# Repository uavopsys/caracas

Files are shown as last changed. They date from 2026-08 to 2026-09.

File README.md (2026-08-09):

# Caracas — Drone Frame

Parametric drone frame model in OpenSCAD, built on the jl_scad project-box
library and BOSL2 (both bundled in `libs/` — no separate install needed).

## Layout

- `caracas.scad` — main model (frame body, arm supports, slice/export logic)
- `libs/` — bundled libraries (`jl_scad`, `BOSL2`, `eazl.scad`); see `libs/ATTRIBUTION.md`

## Rendering

OpenSCAD runs as a flatpak here (`org.openscad.OpenSCAD`, 2021.01):

```bash
# preview (fast, OpenCSG)
flatpak run org.openscad.OpenSCAD -o preview.png --imgsize=800,600 caracas.scad

# export STL (full CGAL render — slow at fine quality; coarsen while iterating)
flatpak run org.openscad.OpenSCAD -D '$fs=0.5' -D '$fa=6' -o caracas.stl caracas.scad
```

## Parts and slices

Top-level variables in `caracas.scad` (also exposed in the Customizer):

- `part` — `"all"` | `"bottom"` | `"middle"` | `"top"`: which frame slice to render
- `explode` — Z gap (mm) between slices in the `part="all"` view; `0` = assembled
- `z_bottom` / `z_middle` / `z_top` — slice heights; `frame_height` is derived
  from them plus `plate_thickness` and `frame_thickness`

Export a single slice for printing:

```bash
flatpak run org.openscad.OpenSCAD -D 'part="middle"' -o middle.stl caracas.scad
```

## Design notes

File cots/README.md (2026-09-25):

# Caracas build123d parts

This folder contains the current Python/build123d CAD models. Running a part
script exports its generated files (`.stl`, `.step`, and, for some scripts,
`.dxf`) into this folder.

## First-time setup

Python 3.11 is required. From this folder, run:

```bash
./setup.sh
source .venv/bin/activate
```

The first command creates a local `.venv` and installs the versions in
`requirements.txt`. The second command activates it for the current shell.
Repeat only the `source` command when opening a new shell.

If `setup.sh` is not executable after copying the project, run it as:

```bash
bash setup.sh
```

## Generate parts

With the virtual environment active, run any part script directly:

```bash
python arm_hub.py
python plate.py
python motor_mount.py
python canopy.py
```

For example, `python plate.py` creates `plate.step`, `plate.stl`, and
`plate.dxf`. Parameter-tagged models such as the arm hub and motor mount put
their dimensions in the output filename. Shared dimensions are read from
`config.yaml`.

Activation is optional if you call the virtual-environment interpreter
explicitly:

```bash
.venv/bin/python arm_hub.py
```

The optional 3D viewer can be started in a second terminal after activation:

```bash
python -m ocp_vscode
```

The exports are still produced when the viewer is not running. The drawing
scripts (`drawing.py` and `standoff_dimensions.py`) create documentation
images/PDFs rather than STL/STEP parts.

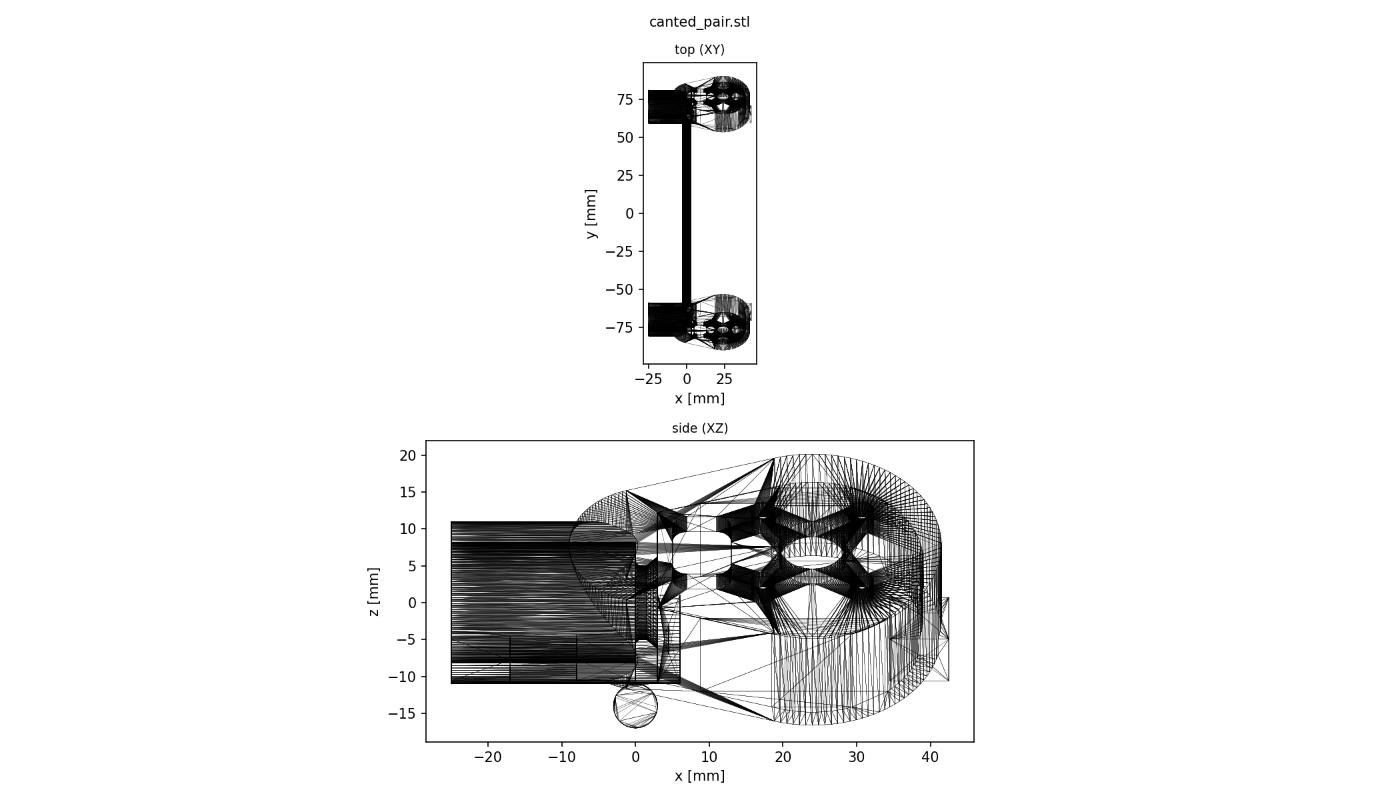
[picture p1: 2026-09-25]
cots/canted_pair_preview.png

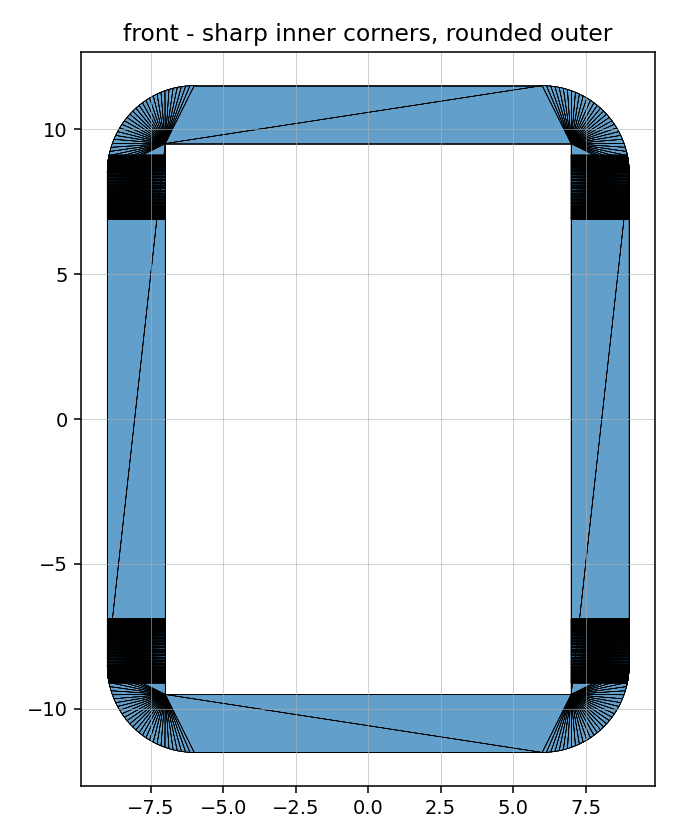
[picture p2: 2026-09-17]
cots/camera_holder_preview.png

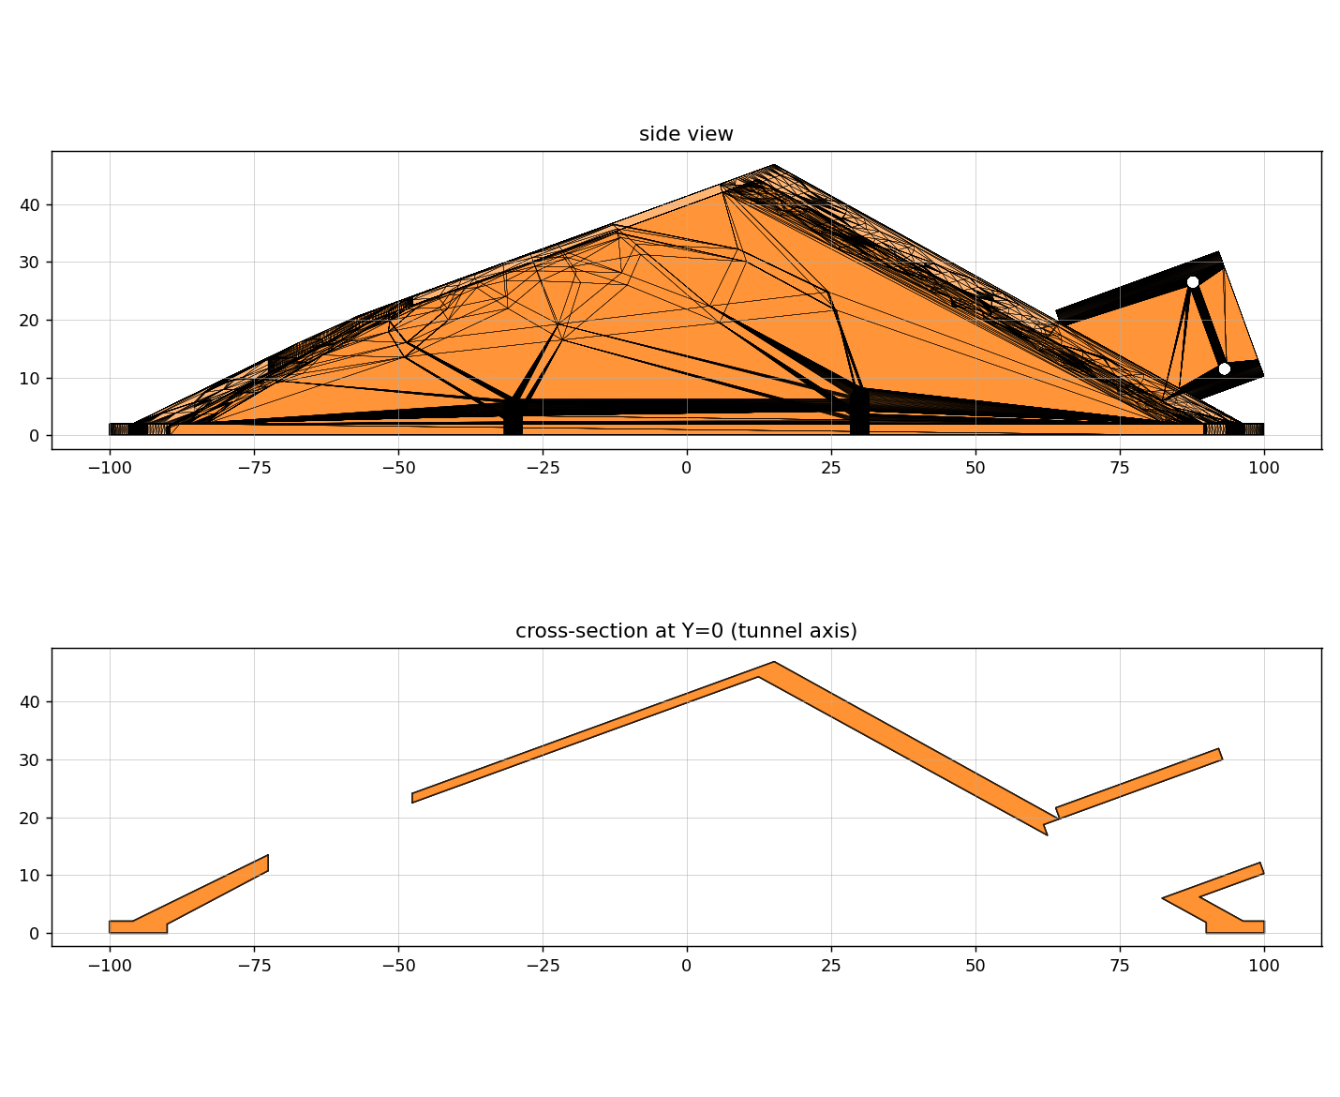
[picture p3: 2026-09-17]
cots/canopy_camera.png

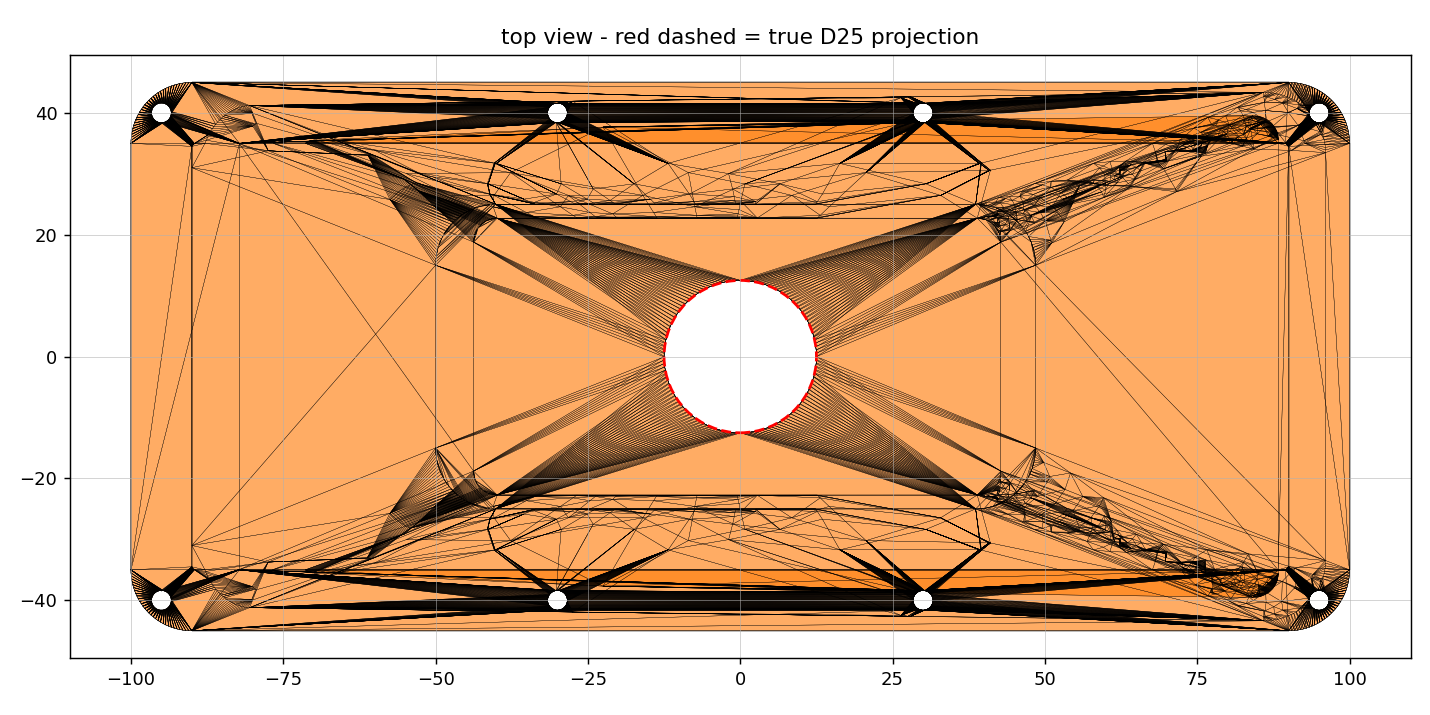
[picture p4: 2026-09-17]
cots/canopy_cutout.png

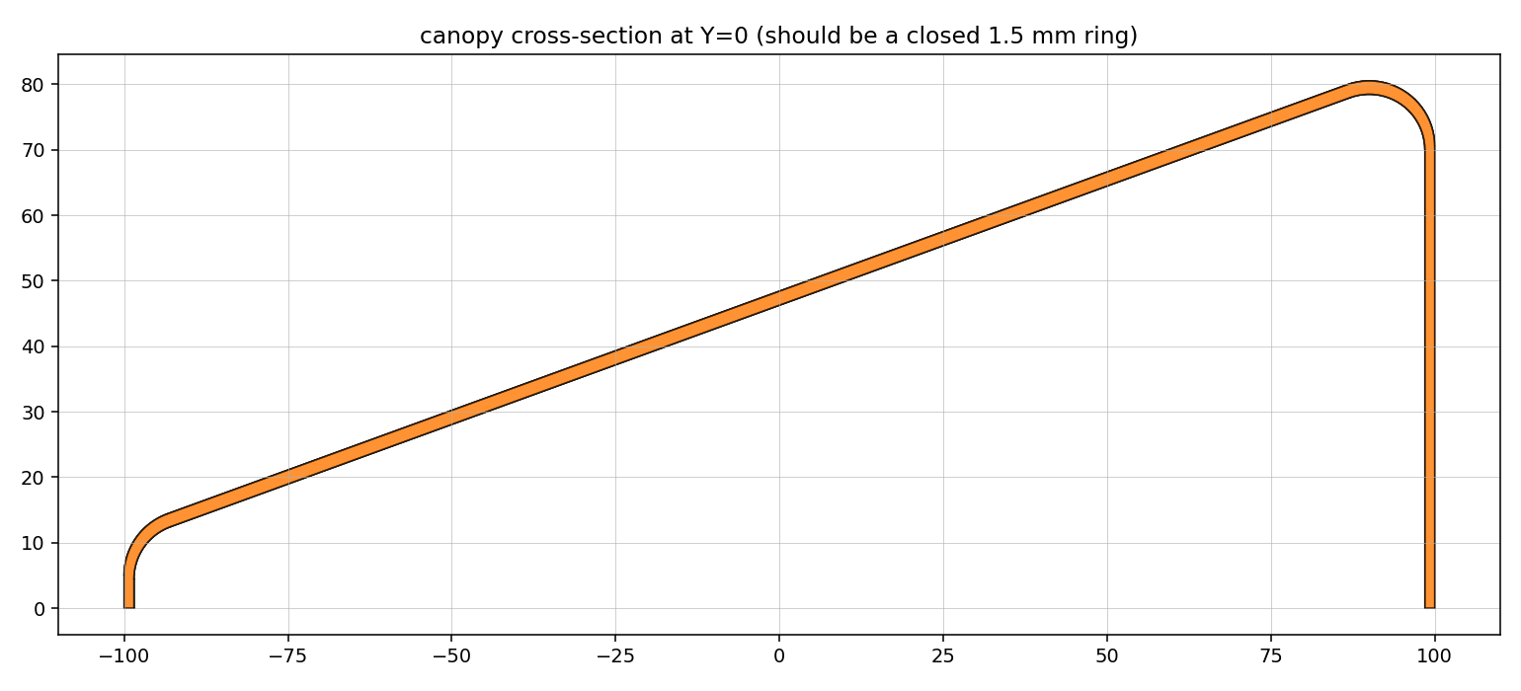
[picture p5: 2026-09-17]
cots/canopy_section.png

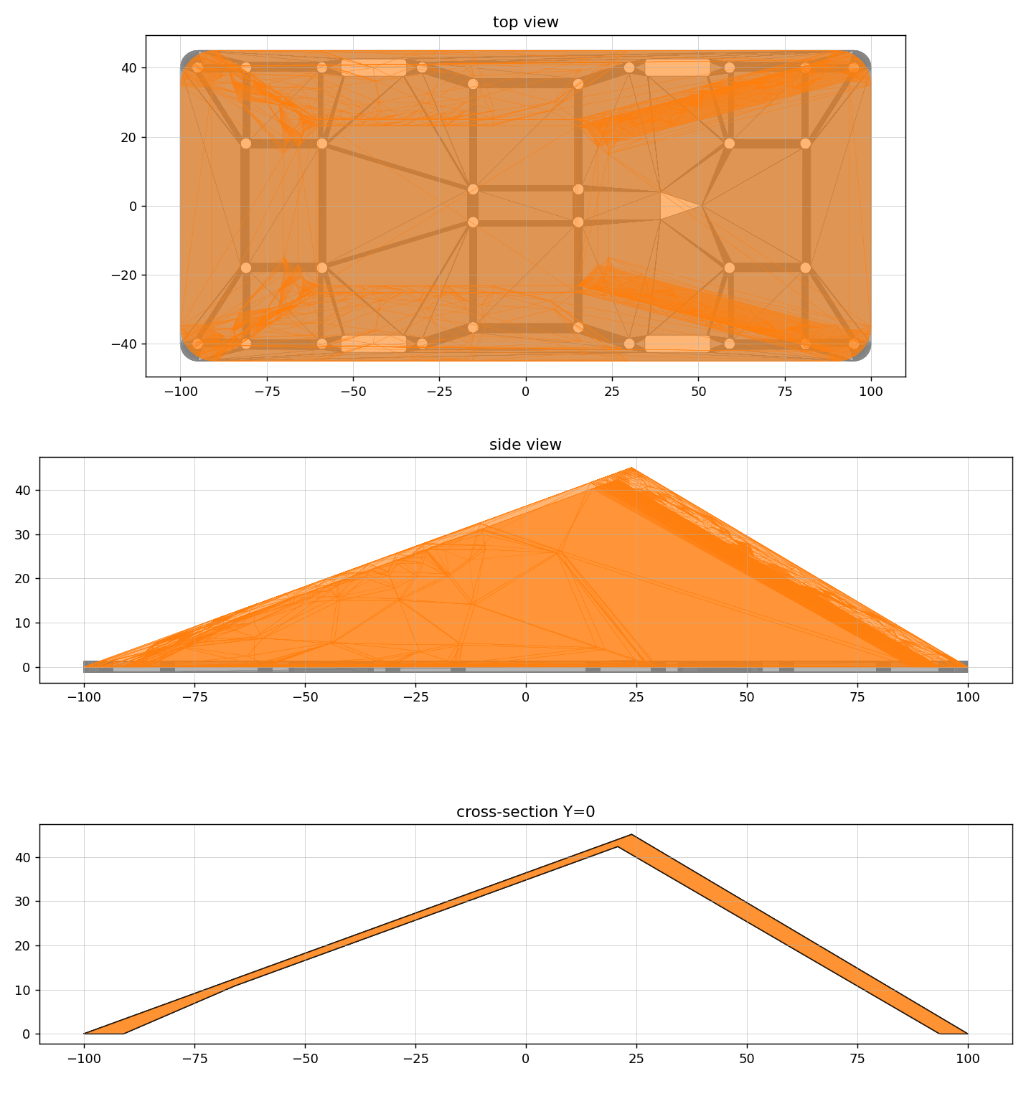
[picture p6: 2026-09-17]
cots/canopy_preview.png

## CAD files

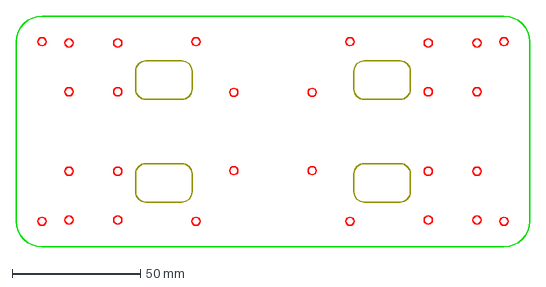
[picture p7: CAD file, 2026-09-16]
mvp/plate.dxf
200.0 x 90.0 mm

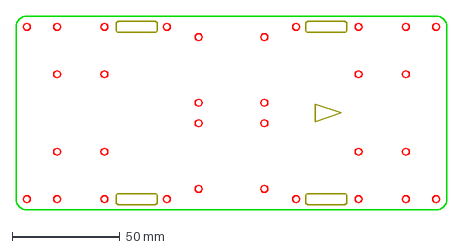
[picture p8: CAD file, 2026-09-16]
cots/plate.dxf
200.0 x 90.0 mm

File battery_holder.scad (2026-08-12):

/**
 * Battery Holder
 * ==============
 * Secure mounting system for FullSend 10A batteries
 *
 * Self-contained: all parameters and helper modules live in this file.
 */

// =============================================================================
// PARAMETERS
// =============================================================================

// FullSend 10A battery dimensions (mm)
BATTERY_LENGTH = 160;
BATTERY_WIDTH = 67;
BATTERY_DEPTH = 47;
BATTERY_CLEARANCE = 2.3;  // inner spacing around battery

// Strap handle dimensions (mm)
STRAP_HANDLE_THICKNESS = 4;
STRAP_HANDLE_WIDTH = 8;
STRAP_HANDLE_HEIGHT = 5;

// =============================================================================
// STRAP HANDLE
// =============================================================================

/**
 * Strap Handle - zip-tie or velcro strap loop
 * Used for securing the battery to the bay
 */
module strap_handle() {
    thickness = STRAP_HANDLE_THICKNESS;
    width = STRAP_HANDLE_WIDTH;
    height = STRAP_HANDLE_HEIGHT;

    difference() {
        // Outer block
        cube([22 + 2*thickness, width, height + thickness], center=true);

        // Inner cutout for strap
        cube([22, width + 1, height], center=true);
    }
}

// =============================================================================
// FULLSEND 10A BATTERY BAY
// =============================================================================

/**
 * FullSend 10A Battery Holder
 *
 * Features:
 *   - Protective enclosure with one open side for easy insertion
 *   - Multiple strap handle positions for secure retention
 *   - Handles on rear, middle-front, and middle-back
 *   - Optimized for 160x65x45mm battery pack
 *
 * Battery Specifications:
 *   - Length: 160mm
 *   - Width: 65mm
 *   - Depth: 45mm
 */
module fullsend10a_battery_bay() {
    inner_space = BATTERY_CLEARANCE;
    batt_length = BATTERY_LENGTH;
    batt_width = BATTERY_WIDTH;
    batt_depth = BATTERY_DEPTH;

    // =========================================================================
    // Main Battery Enclosure
    // =========================================================================

    difference() {
        // Outer shell
        cube([
            batt_length + 2*inner_space,
            batt_width + 2*inner_space,
            batt_depth + 2*inner_space
        ], center=true);

        // Inner cavity (offset for single open side)
        translate([inner_space, 0, 0])
            cube([
                batt_length + inner_space,
                batt_width,
                batt_depth
            ], center=true);
    }

    // =========================================================================
    // Strap Handles - Rear Position
    // =========================================================================

    // Rear left handle
    rotate([0, -90, 0])
        translate([10, batt_width/2 + 5, -batt_length/2 - 5])
            strap_handle();

    // Rear right handle
    rotate([0, -90, 0])
        translate([10, -batt_width/2 - 5, -batt_length/2 - 5])
            strap_handle();

    // =========================================================================
    // Strap Handles - Middle-Front Position (Bottom)
    // =========================================================================

    // Front-left position 1
    translate([batt_length/12, -batt_width/2 - 5, -batt_depth/2 + 1.75])
        rotate([90, 0, 0])
            strap_handle();

    // Front-left position 2
    translate([-batt_length/12, -batt_width/2 - 5, -batt_depth/2 + 1.75])
        rotate([90, 0, 0])
            strap_handle();

    // Front-left position 3
    translate([batt_length/4, -batt_width/2 - 5, -batt_depth/2 + 1.75])
        rotate([90, 0, 0])
            strap_handle();

    // Front-left position 4
    translate([-batt_length/4, -batt_width/2 - 5, -batt_depth/2 + 1.75])
        rotate([90, 0, 0])
            strap_handle();

    // =========================================================================
    // Strap Handles - Middle-Back Position (Top)
    // =========================================================================

    // Back-right position 1
    translate([batt_length/12, batt_width/2 + 5, -batt_depth/2 + 1.75])
        rotate([90, 0, 0])
            strap_handle();

    // Back-right position 2
    translate([-batt_length/12, batt_width/2 + 5, -batt_depth/2 + 1.75])
        rotate([90, 0, 0])
            strap_handle();

    // Back-right position 3
    translate([batt_length/4, batt_width/2 + 5, -batt_depth/2 + 1.75])
        rotate([90, 0, 0])
            strap_handle();

    // Back-right position 4
    translate([-batt_length/4, batt_width/2 + 5, -batt_depth/2 + 1.75])
        rotate([90, 0, 0])
            strap_handle();
            
    // ======================================================================
    // wire passage
    // ======================================================================
    translate([0, batt_width/2-3 , -batt_depth/2 - 7])
        cube ([batt_length,10,12],center=true);
    translate([0, -batt_width/2+3, -batt_depth/2 -7])
        cube ([batt_length,10,12],center=true);


}

// =============================================================================
// USAGE EXAMPLES (uncomment to render)
// =============================================================================

// Render battery bay
fullsend10a_battery_bay();

// =============================================================================
// PRINTING NOTES
// =============================================================================

/*
 * Recommended Print Settings:
 *   - Layer Height: 0.2mm - 0.3mm
 *   - Wall Count: 3-4 perimeters
 *   - Infill: 20-30% gyroid or honeycomb
 *   - Support: May need support for strap handles depending on orientation
 *
 * Recommended Orientation:
 *   - Print with battery opening facing up for minimal supports
 *   - Strap handles may need light support material
 *
 * Post-Processing:
 *   - Test fit battery before installing
 *   - Use 20-25mm wide velcro/battery straps
 *   - Ensure clearance is adequate (adjust BATTERY_CLEARANCE above if needed)
 */

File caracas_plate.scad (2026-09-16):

include <libs/jl_scad/utils.scad>
include <libs/jl_scad/box.scad>
include <libs/jl_scad/parts.scad>

// caracas plate
frame_width=90;
frame_length=200;
plate_thickness=2.5;
case_rounding=25;



module m3_hole(){
    cylinder(h=10,d=3.2,center=true);
}


module foldable_axis(){
        hole_distance=22;
        m3_hole = 3.1;
        
        rotate([0,0,90]) 
        {
            translate([0,hole_distance,0]) cylinder(h=plate_thickness*2,r=m3_hole/2,center=true);
            translate([0,-hole_distance,0]) cylinder(h=plate_thickness*2,r=m3_hole/2,center=true);
        }
        translate([0, -hole_distance,0]) rotate([0,0,90]) 
        {
            translate([0,hole_distance,0]) cylinder(h=plate_thickness*2,r=m3_hole/2,center=true);
            translate([0,-hole_distance,0]) cylinder(h=plate_thickness*2,r=m3_hole/2,center=true);
        }
 
}


 // one plate sized to the shell cross-section at height z (its center)
module support_plate() {
    cuboid([frame_length, frame_width , plate_thickness],
           rounding=case_rounding, edges="Z");
}

module support_holes(){
    
}
support_plate();
translate ([10,0,10]) foldable_axis();

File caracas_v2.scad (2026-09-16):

/**
 * Caracas - Drone Frame
 * =====================
 * Uses the jl_scad project-box library (built on BOSL2)
 * for cases, bodies and rounded curvature.
 */

include <libs/jl_scad/utils.scad>
include <libs/jl_scad/box.scad>
include <libs/jl_scad/parts.scad>

// battery bay module (modules only — its own top-level render call is not executed)
use <battery_holder.scad>

$fs = $preview ? 0.5 : 0.125;
$fa = 5;

// =============================================================================
// PARAMETERS — everything tunable lives in this block
// =============================================================================

// ---- props & frame ----
prop_size       = 110;           // prop radius; 8 inch ≈ 110mm
frame_length    = prop_size*2;   // keeps propellers from colliding
frame_width     = 100;
frame_thickness = 3;             // case wall thickness
case_rounding   = 25;            // case corner rounding

// ---- support plates (carbon fiber) ----
plate_thickness = 2.5;
plate_clearance = 5;             // per-side gap from the case shell

// ---- slice heights ----
z_top    = 30;  // top slice; 28 to make space for folding arms
z_middle = 45;  // middle slice (centered on z=0); 45 to make space for battery
z_bottom = 30;  // bottom slice

// ---- arms (carbon rods) ----
arms_inner_diameter = 16;        // rod diameter
arms_wall_thicklness = 3;        // support wall strength
arms_support_length = 30;
arms_from_edge = prop_size/2-10;      // rod distance from frame end (keeps prop out of sight)

// arm pairs: A+D is one rod (+x), B+C is one rod (-x).
// z is referenced from the "top"/"bottom" outer face; _z_off = mm inward from it.
// e.g. ref="top", off=5 puts the rod 5mm below the top face.
arm_ad_x     = frame_length/2 - arms_from_edge;
arm_ad_z_ref = "top";
arm_ad_z_off = z_top/2+arms_wall_thicklness-plate_thickness;

arm_bc_x     = -(frame_length/2 - arms_from_edge);
arm_bc_z_ref = "bottom";
arm_bc_z_off = z_bottom/2+arms_wall_thicklness-plate_thickness;


// ---- battery bay (separate printed part, fit-check only) ----
show_battery_bay = false;        // also toggles the d_parts() visual guides
show_props = false;        // toggle proppeler view
battery_bay_pos  = [0, 0, 0];    // bay center in frame coords (mm)

// ---- view ----
show_support_plates = true;
part      = "all";               // "all" | "bottom" | "middle" | "top"
explode   = 50;                  // z gap between slices when part="all" (0 = assembled)
explode_y = 200;                   // slides fit-check parts out in y (plates +y, bay -y)

// ---- battery reference dims (unused by the model; bay dims live in battery_holder.scad)
battery_width  = 65;             // iflight fullsend battery
battery_height = 45;
battery_length = 160;

// =============================================================================
// DERIVED VALUES — computed from the parameters above; do not edit directly
// =============================================================================

frame_height = frame_thickness+z_top+plate_thickness+z_middle+plate_thickness+z_bottom+frame_thickness;

arm_ad_z = arm_z(arm_ad_z_ref, arm_ad_z_off);
arm_bc_z = arm_z(arm_bc_z_ref, arm_bc_z_off);

shell_rim_z = frame_height/2 - case_rounding;  // height where the shell starts curving in



// hollow cylinder: inner D 16, wall 5, length 10, rounded rims
// (rounding is capped at wall/2 = 2.5)
module arm_support(height){
    depth= (frame_width-frame_thickness*1.5)/2;
        rotate([-90,90,0]){
            translate([0,0,-arms_support_length/4])tube(id=arms_inner_diameter, wall=arms_wall_thicklness, h=arms_support_length, rounding=2, center=true);
            *translate([0,0,depth/2])cube([arms_inner_diameter*2, (frame_width-frame_thickness*1.5)/2, height],center=true);
        }

}


module body() {
    
difference(){
    union(){
        // 20x20x20 cube with curvature on all sides
        difference(){
            cuboid([frame_length, frame_width, frame_height], rounding=case_rounding);
                    // hollow the case — inner rounding shrinks by the wall thickness
                    // so the shell stays a uniform 6mm, closed at top/bottom
            cuboid([frame_length-frame_thickness*1.5, frame_width-frame_thickness*1.5, frame_height-frame_thickness*2],
                   rounding=case_rounding-frame_thickness);
        }
    
    
        arm_pair_ad();  // A front, D back — one rod
        arm_pair_bc();  // B front, C back — one rod
    }          

// open the walls where the arms will go
translate([arm_ad_x,0,arm_ad_z]) rotate([90,0,0]) cylinder(h=500,d=16,center=true);
translate([arm_bc_x,0,arm_bc_z]) rotate([90,0,0]) cylinder(h=500,d=16,center=true);
}
    
}





// ---- arm pairs --------------------------------------------------------
// Arms are carbon fiber rods in an H configuration; each pair (A+D, B+C)
// is one continuous rod held by two supports. Placement params are at the top.
function arm_z(ref, off) = ref == "top" ? frame_height/2 - off
                                        : -frame_height/2 + off;

// explode offset of the slice a pair belongs to (top slice moves up, bottom down)
function pair_explode(ref) = part == "all" ? (ref == "top" ? explode : -explode) : 0;

module arm_pair_ad() {
    h = arm_ad_z_ref == "top" ? z_top : z_bottom;
    //A (front)
    translate([arm_ad_x,-frame_width/2+frame_thickness,arm_ad_z]) arm_support(height=h);
    //D (back)
    translate([arm_ad_x,frame_width/2-frame_thickness,arm_ad_z]) rotate([180,0,0]) arm_support(height=h);
}

module arm_pair_bc() {
    h = arm_bc_z_ref == "top" ? z_top : z_bottom;
    //B (front)
    translate([arm_bc_x,-frame_width/2+frame_thickness,arm_bc_z]) arm_support(height=h);
    //C (back)
    translate([arm_bc_x,frame_width/2-frame_thickness,arm_bc_z]) rotate([180,0,0]) arm_support(height=h);
}

// ---- support plates (carbon fiber — separate parts, not printed) ------
// Four plates: one inside the top case, one on each side of the middle
// cut, one inside the bottom case. Each plate follows the case shell
// cross-section at its own height: middle plates sit where the shell is
// full-size; top/bottom plates where it has curved inward — so smaller.
// Params (plate_thickness, plate_clearance, show_support_plates) are at the top.

// shell cross-section at height z: inward offset and corner radius there
function shell_inset(z)  = abs(z) <= shell_rim_z ? 0
    : case_rounding - sqrt(case_rounding*case_rounding - pow(abs(z) - shell_rim_z, 2));
function shell_corner(z) = abs(z) <= shell_rim_z ? case_rounding
    : sqrt(case_rounding*case_rounding - pow(abs(z) - shell_rim_z, 2));

// one plate sized to the shell cross-section at height z (its center)
module support_plate(z) {
    inset = shell_inset(z) + plate_clearance;
    cuboid([frame_length - 2*inset, frame_width - 2*inset, plate_thickness],
           rounding=max(0, shell_corner(z) - plate_clearance), edges="Z");
}


module m3_hole(){
    cylinder(h=10,d=3.2,center=true);
}


module pattern(){
      x_shift=50;
      y_shift=15;
      z_rotate = 10;
    
      translate([x_shift,0,0]){
      rotate([0,0,z_rotate]) translate([0,y_shift,0]) cuboid([50,10,30], rounding=3, edges="Z");
      rotate([0,0,-z_rotate]) translate([0,-y_shift,0]) cuboid([50,10,30], rounding=3, edges="Z");
      }
      translate([-x_shift,0,0]){
      rotate([0,0,z_rotate]) translate([0,y_shift,0]) cuboid([50,10,30], rounding=3, edges="Z");
      rotate([0,0,-z_rotate]) translate([0,-y_shift,0]) cuboid([50,10,30], rounding=3, edges="Z");
      }



}

**translate ([0,explode_y,100]) pattern();



module foldable_axis(){
        hole_distance=22;
        padding = 6;
        m3_hole = 3.1;
        radius=hole_distance*cos(45/2)+padding+m3_hole;
        thickness=plate_thickness*1.5;
        
        difference(){
            cylinder(h=thickness,r=radius,center=true);
            translate([0,hole_distance*cos(45/2),0]) cylinder(h=plate_thickness*2,r=m3_hole/2,center=true);
            translate([0,-hole_distance*cos(45/2),0]) cylinder(h=plate_thickness*2,r=m3_hole/2,center=true);
            translate([hole_distance*cos(45/2),0,0]) cylinder(h=plate_thickness*2,r=m3_hole/2,center=true);
            translate([-hole_distance*cos(45/2),0,0]) cylinder(h=plate_thickness*2,r=m3_hole/2,center=true);
        }

}

translate([100,100, 20]) foldable_axis();

module support_plates() {
    z_in   = frame_height/2 - frame_thickness;   // inner top/bottom face of the case
    zc_tb  = z_in - plate_thickness/2;           // true center of the top/bottom plates
    zc_mid = z_middle/2 + plate_thickness/2;     // true center of the middle plates

    //top
    translate([0,0,  zc_tb + pair_explode("top")])    support_plate(zc_tb);
    *translate([0,frame_width/3,  zc_tb + pair_explode("top")]) m3_hole();
    *translate([0,-frame_width/3,  zc_tb + pair_explode("top")]) m3_hole();
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

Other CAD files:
caracas.scad

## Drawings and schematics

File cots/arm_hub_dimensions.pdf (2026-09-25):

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

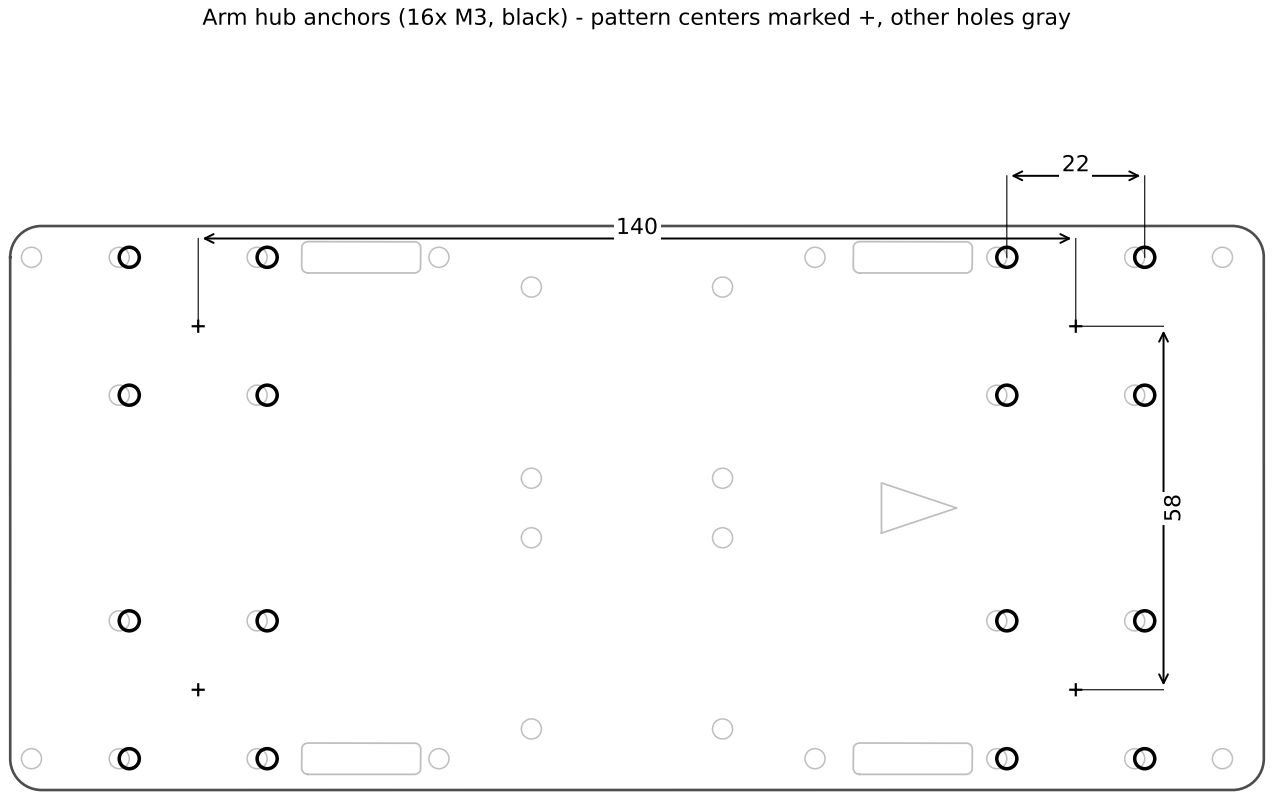
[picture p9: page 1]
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

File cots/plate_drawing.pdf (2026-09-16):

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

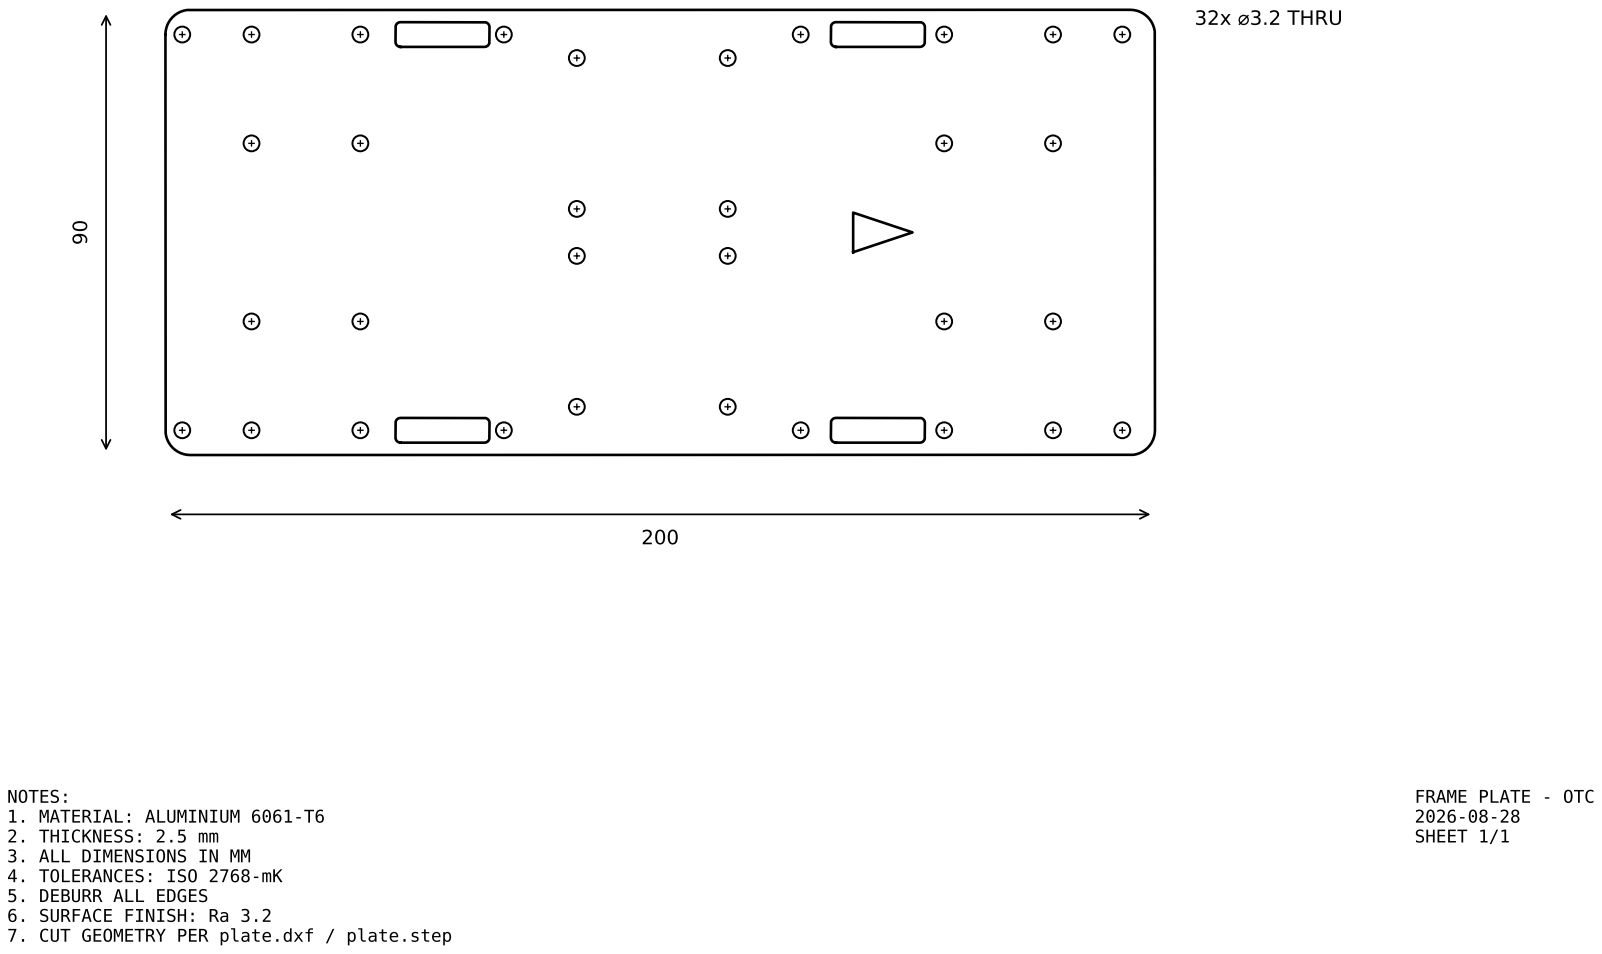
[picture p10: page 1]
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

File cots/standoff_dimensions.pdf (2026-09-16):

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

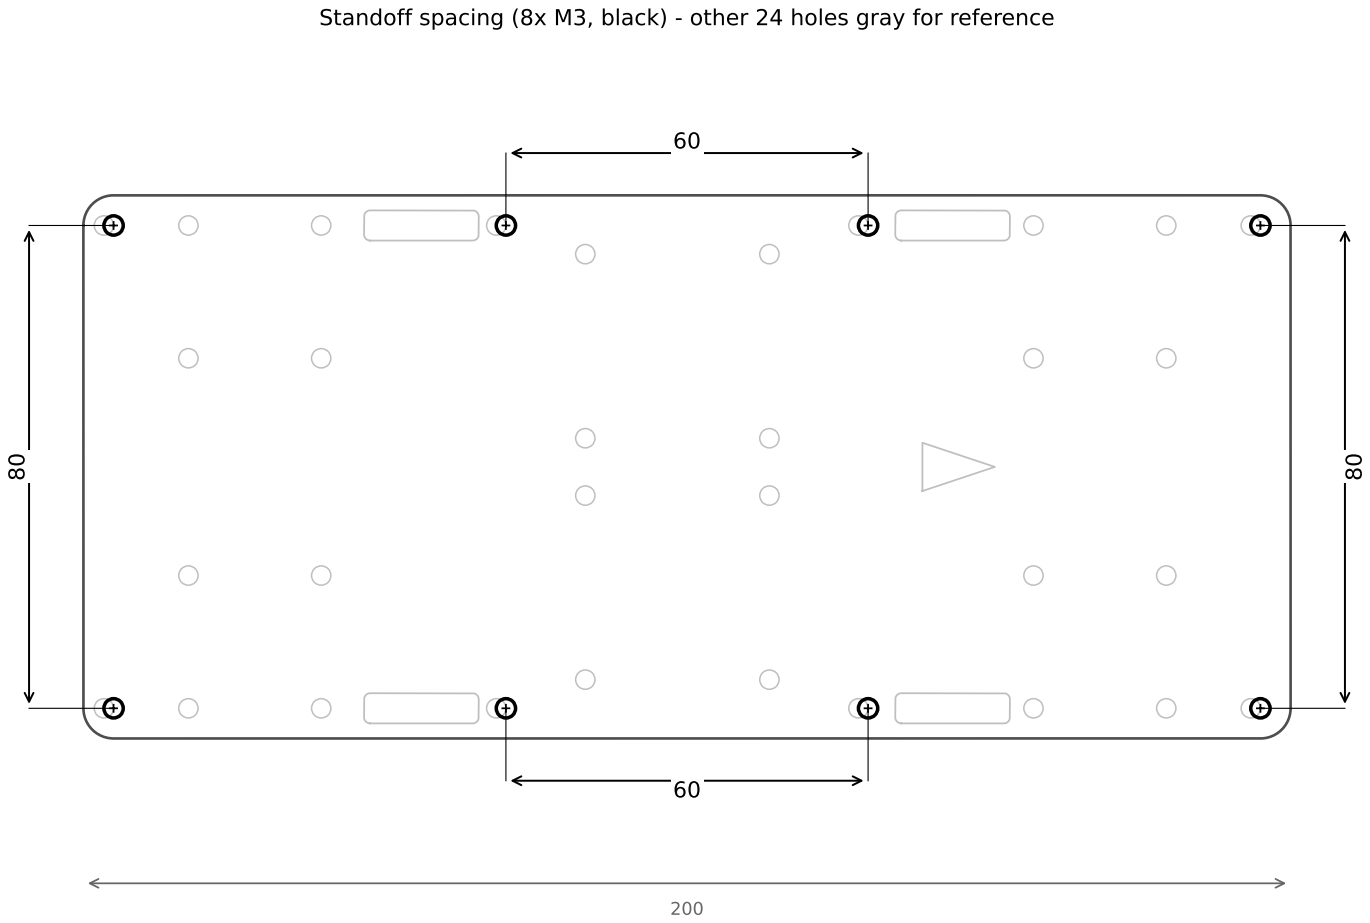
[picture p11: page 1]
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

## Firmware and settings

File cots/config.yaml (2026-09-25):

# COTS variant configuration.
# Values that more than one script must agree on live here; scripts compute
# derived values themselves (e.g. plate.py derives pattern positions from
# hole_grid and corner_standoff_offset).
# The jigs read geometry from plate.step, so they need nothing from this file.

# Arm hub: block holding the D16 carbon rod, bolts onto the plate corners.
arm_hub:
  size: 28            # block edge (X/Y)
  size_height: 22     # block height (Z)
  rod_diameter: 16    # through-bore for the carbon rod (D16)
  rod_clearance: 0.4  # shared arm-tube bore clearance (hub + motor mount)
  screw_diameter: 3   # M3 self-tapping pilot for printed plastic (no insert)
  hole_grid: 22       # 2x2 screw spacing; plate anchor patterns align to this

# Plate: carbon fiber main plate.
plate:
  # ---- plate ----
  frame_length: 200
  frame_width: 90
  plate_thickness: 2.5
  corner_rounding: 5

  # ---- M3 anchor patterns (one per corner) ----
  screw_diameter: 3.2   # M3 clearance (2.5 for tapping)
  pattern_x: 30         # pattern center distance from the plate end (short) edge
  # pattern rotation in degrees. Forward pair: port CCW, starboard CW.
  # Aft pair: reversed (port CW, starboard CCW). Nose is +X, port is +Y.
  pattern_angle_forward: 0
  pattern_angle_aft: 0

  # ---- standoff holes (8 total: 4 corner + 4 middle) ----
  standoff_diameter: 3.2          # M3 standoff screws
  corner_standoff_offset: 5       # corner hole center distance from each edge
  middle_standoff_edge_offset: 5  # middle hole center distance from the long edge
  middle_standoff_x: 30           # middle hole distance from plate center along X

  # ---- flight controller mounts: concentric M3 grids,
  #      mirrored across the centerline so either side can take a stack ----
  fc_pattern_spacings: [30.5]
  # fc_pattern_spacings: [30.5, 25.5, 20]  # uncomment to add 25.5 + 20 grids
  fc_hole_diameter: 3.2
  fc_x: 0               # pattern center along the length
  fc_y: 20              # pattern center along the width
  fc_mirror: true       # duplicate the patterns on the mirror side (y -> -y)

  # ---- lightening slots (weight reduction in the low-stress web) ----
  lightening: true
  slot_length: 19       # along X
  slot_width: 5        # along Y
  slot_radius: 1        # corner fillet - generous radii, sharp corners start cracks
  slot_gap_from_anchor: 26  # slot center this far inward from the anchor pattern
  slot_y: 40

  # ---- forward marker: small arrow cut into the web, points at the nose (+X) ----
  fwd_arrow: true
  arrow_x: 45           # arrow center along the length, on the centerline
  arrow_size: 12        # overall arrow length
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

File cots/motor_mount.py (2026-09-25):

"""
D16 'droplet' motor mount - teardrop shell cantilevered past the END of the
16mm carbon arm tube, carrying a 2812-size brushless motor on a flat
platform. The whole part lives inside the arm hub's vertical envelope:
centered bore at z=0, platform top at exactly +size_height/2 (11mm), nothing
below -size_height/2 (-11mm). Flush tops and bottoms with the arm hub ARE
the leveling mechanism (see below).

Geometry (shared values from config.yaml; the arm tube dimensions come from
the arm_hub section and mount-specific values from motor_mount):
- BLIND bore (glue well) = rod_diameter + rod_clearance = 16.4mm: the tube
  inserts insertion_depth (25mm) from the hub-facing end and bottoms against
  a stop face. Past the stop a 10mm hole opens into the droplet's hollow
  cavity, so the carbon tube's open end faces the cavity - the motor cable
  gets into the tube through it, no drilling.
- teardrop plan along the tube axis: round end (2 x droplet_radius, ~35mm
  across) carries the motor, tapering back to the D22 sleeve. Platform skin
  (3mm) at z=+11: 4x 3.2mm holes on a 19mm bolt circle at 45/135/225/315 deg
  (from skyfold's motor_adapter_19_25.scad), a 9mm center hole, and the cable
  opening (rounded rectangle, cable_slot_width x cable_slot_x1-x0) BETWEEN
  the bolt circle and the arm - like the classic aluminum clamp mounts, the
  motor leads exit the motor's rear edge and drop straight through into the
  cavity, then through the stop hole into the tube. No bend, no exposed wire.
- open bottom: a perimeter skirt (skirt_thickness) follows the droplet
  outline from the skin underside down to skirt_bottom_z like a shallow boat
  hull; the cavity is open from below so the M3 bolt heads (bolts come up
  from below into the motor's threaded base) are accessible. Two side ribs
  stiffen the skin, clear of the cable raceway and the head envelopes.
- leveling feet: three foot_size squares with bottoms at exactly z=-11 - a
  3-point stance (the round sleeve alone can't sit flat). Leveling: set the
  mount on a flat table next to the arm hub (or press both against a
  straightedge) while the epoxy cures; flush bottoms (-11) and tops (+11)
  guarantee rotational alignment.
- cable funnel: trumpet flare (10 -> 15mm) on the cavity side of the stop
  hole plus a small rim chamfer on the tube side, so wires feeding into the
  tube end are guided and the tube tip doesn't catch a sharp rim.

Print: platform skin DOWN on the bed (part flipped from its installed
orientation), bore axis horizontal - the open cavity faces up and needs no
supports; the blind bore prints as a horizontal hole, hence rod_clearance
0.4mm total for bridging sag (same reasoning as arm_hub.py).

Run with the ocp_vscode standalone viewer running (python3.11 -m ocp_vscode),
or headless: exports motor_mount-<rod_diameter>-<rod_clearance>.step/.stl
next to this file.
"""

import math
import os
from pathlib import Path

import yaml
from build123d import *

os.chdir(Path(__file__).parent)  # outputs land next to this script

# =============================================================================
# PARAMETERS — from config.yaml
# =============================================================================

with open("config.yaml") as f:
    config = yaml.safe_load(f)

cfg = config["motor_mount"]
arm_cfg = config["arm_hub"]

rod_diameter = arm_cfg["rod_diameter"]    # shared D16 carbon arm tube
rod_clearance = arm_cfg["rod_clearance"]  # shared horizontal-bore clearance
sleeve_diameter = cfg["sleeve_diameter"]  # ~3mm wall over the rod
insertion_depth = cfg["insertion_depth"]  # blind bore: tube bottoms against the stop
stop_hole_diameter = cfg["stop_hole_diameter"]  # cable pass at the bore's inner end
droplet_radius = cfg["droplet_radius"]    # round end carrying the motor
droplet_center_x = cfg["droplet_center_x"]  # round end center, outboard of the stop
skin_thickness = cfg["skin_thickness"]    # platform top skin
skirt_thickness = cfg["skirt_thickness"]  # perimeter wall around the open cavity
skirt_bottom_z = cfg["skirt_bottom_z"]    # skirt lower edge; cavity open below
motor_bcd = cfg["motor_bcd"]              # 2812 bolt circle, 4x M3 at the 45 deg diagonals
motor_hole_diameter = cfg["motor_hole_diameter"]
center_hole_diameter = cfg["center_hole_diameter"]
cable_slot_x0 = cfg["cable_slot_x0"]  # cable opening, tube-side end
cable_slot_x1 = cfg["cable_slot_x1"]  # motor-side end (behind the rear bolt holes)
cable_slot_width = cfg["cable_slot_width"]
foot_size = cfg["foot_size"]              # 3 leveling feet

# vertical envelope: the arm hub is a size x size x size_height block with a
# centered bore, so its faces sit at +/- size_height/2 - the mount shares both
# planes (platform top at +env, feet bottoms at -env).
env = config["arm_hub"]["size_height"] / 2  # 11.0

# =============================================================================
# DERIVED
# =============================================================================

bore_diameter = rod_diameter + rod_clearance  # 16.4
bore_radius = bore_diameter / 2
sleeve_radius = sleeve_diameter / 2

skin_top_z = env                       # platform top: flush with the arm hub top
skin_bottom_z = skin_top_z - skin_thickness

# X layout: the bore stop face is at x=0; the tube/sleeve extends in -X
# (toward the arm hub), the droplet cantilevers outboard in +X.
sleeve_x0 = -insertion_depth           # tube entry face
stop_x1 = 3                            # stop wall thickness: x 0..3
funnel_x1 = 6                          # cable funnel: x 3..6
sleeve_x1 = funnel_x1                  # sleeve reaches into the droplet neck
neck_x = 2                             # teardrop neck circle center (on the sleeve)

hole_xy = motor_bcd / (2 * math.sqrt(2))  # hole center on each axis (+/-6.72)
motor_x = droplet_center_x             # motor pattern center
skin_mid_z = (skin_bottom_z + skin_top_z) / 2  # cuts centered here pierce the skin
slot_cx = (cable_slot_x0 + cable_slot_x1) / 2
slot_len = cable_slot_x1 - cable_slot_x0

# M3 socket head envelope (heads sit in the open cavity under the skin)
head_diameter = 5.5
head_height = 3.0

# ribs stiffening the skin: along X at the cavity sides, clear of the cable
# raceway (|y| <= 5 around the stop hole) and of the head envelopes (rim at
# |y| = hole_xy + head_diameter/2 = 9.47)
rib_y0 = 11
rib_thickness = 3

# leveling feet: two on the sleeve fore/aft, one under the droplet tip
feet = [(sleeve_x0 + 4, 0), (-4, 0), (droplet_center_x + droplet_radius - foot_size / 2 + 1, 0)]

# =============================================================================
# PART
# =============================================================================
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

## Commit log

2026-08-09 initial: caracas drone frame (body, arm supports, 3-slice z export)
    [caracas.scad]
2026-08-12 import speedybee fold 8 battery bay sources (reference snapshot)
    [FPV_Leg.scad, battery_holder.scad, common_modules.scad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]
2026-08-12 battery bay self-contained; arm pairs, support plates, fit-check overlays in caracas
    - battery_holder.scad: inline config constants + strap_handle, drop speedybee includes
    - remove speedybee scaffold files (config/common_modules/FPV_Leg)
    - caracas.scad: parametric arm pairs (A+D, B+C) with top/bottom z reference,
    visual guides follow z-explode; battery bay + 4 carbon support plates as
    togglable fit-check overlays; explode_y slides overlays out sideways
    [FPV_Leg.scad, battery_holder.scad, caracas.scad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]
2026-09-16 track cots/mvp build123d work, root scad/py sources; ignore CAD exports (stl/step/3mf)
    [caracas_plate.scad, caracas_v2.scad, plate.dxf]
2026-09-17 add canopy, camera_holder, gps_holder to cots; shared config.yaml
    canopy.py: config-driven lofted pod - top plate driven by top_height +
    optional slope_angle, tail exhaust slots, NACA roof ducts, rounded side
    service openings between the middle standoffs (USB/button access), and
    flange cutouts exposing the plate's lightening slots with the channel
    reaching inward for cable routing. Positions follow plate config.
    camera_holder.py / gps_holder.py: standalone sleeve and arc-band parts.
    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
2026-09-20 canopy: standoff screw seats, 160x60x30 top, 28mm cutout
    Pads with head seats per standoff hole plus access wells through the
    shell so screws drop straight in and clamp the pod against vibration;
    top plate grows to 160x60 at 30mm height, projected cutout to 28mm.
    [config.yaml]
2026-09-20 motor_mount: D16 'droplet' motor mount for tube-end installation
    Teardrop shell cantilevered past the end of the 16mm carbon arm tube,
    carrying a 2812 motor (4x M3 on 19mm BCD, from skyfold's adapter). The
    part lives inside the arm hub's vertical envelope: platform top flush
    with the hub top (+11mm), three leveling feet flush with the hub bottom
    (-11mm) - flush bottoms on a flat table ARE the leveling mechanism.
    - blind bore D16.4 x 25mm = epoxy glue well, no screws
    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
2026-09-25 Add canted-pair jig, arm hub dimension drawing, and project setup files
    - canted_pair.py: composite jig, two motor mounts at 140mm (hub center
    distance) canted +/-45 deg about their bore axes, joined by a printed
    D6 rod at the sleeve-entry plane (U shape) for the canted-motor test
    - arm_hub_dimensions.py: plate drawing calling out the 4 arm-hub anchor
    patterns (140 x 58 centers, 22 grid)
    - stl_preview.py: 2D top/side wireframe STL preview (mplot3d is broken)
    - motor_mount.py / config.yaml: share rod_diameter + rod_clearance from
    the arm_hub section; bump clearance 0.3 -> 0.4
    - setup.sh, requirements.txt, README.md, .gitignore: venv-based setup
    (python3.11 + build123d + ocp-vscode)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
    [config.yaml, motor_mount.py]
